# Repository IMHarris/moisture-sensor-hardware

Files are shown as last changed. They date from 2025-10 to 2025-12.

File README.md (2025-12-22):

# Moisture Sensor Hardware

KiCad hardware design for ESP32-based soil moisture monitoring system.

## Overview

This repository contains the PCB design and schematics for an irrigation moisture sensor system. The board interfaces with resistance-based moisture sensors ([I recommend Irrometer Watermark Sensors](https://www.irrometer.com/sensors.html)) and DS18B20 temperature sensors.

The board uses an [SMX moisture sensor interface](https://www.emesystems.com/smx/main.html) board to interact with up to 6 moisture sensors. The SMX board transmits AC power to the sensors which substantially reduces mineral accumulation and extends the life of the sensors.  Because moisture sensors are sensitive to temperature, the board also can take in data from DS18B20 temperature sensors through 2 available 1-Wire bus inputs.

The ESP 32 firmware combines moisture sensor and soil temperature outputs to calculate soil tension values for use in irrigation systems.  The firmware can be configured with wifi credentials so the user can access the board's web server which will display sensor values.  The firmware can also be configured with mqtt message server credentials allowing the board to transmit sensor data in formatted json via wifi to your main irrigation controller.  I am using the [SIP controller](https://github.com/Dan-in-CA/SIP) for my main irrigation system.

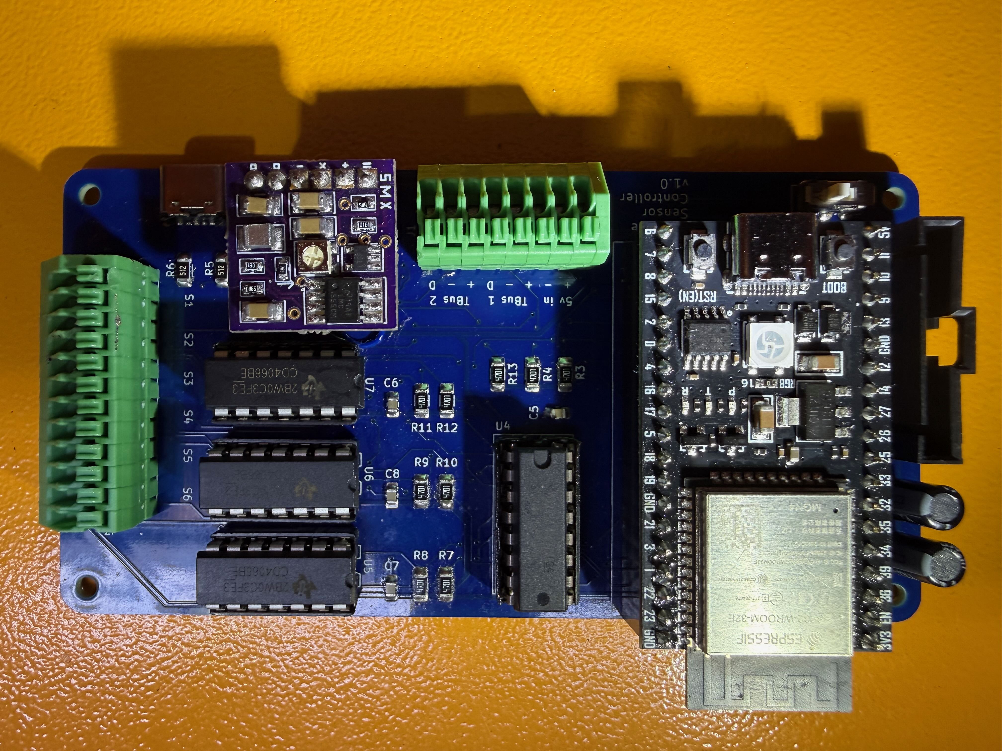
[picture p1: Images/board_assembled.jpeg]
Fully assembled board


*Board fabrication done by [PCBWay](https://www.pcbway.com) whom I can't say enough good things about: excellent website, great communication, and outstanding quality.  Their KiCad plugin makes design file uploads super easy.

## Firmware

Firmware for this hardware is available in a separate repository:
**[moisture-sensor-esp32](https://github.com/IMHarris/moisture-sensor-esp32)**

## Design Files

- **`MoistureSensor1.kicad_pro`**: KiCad project file
- **`MoistureSensor1.kicad_sch`**: Schematic design
- **`MoistureSensor1.kicad_pcb`**: PCB layout
- **`MoistureSensor1BOM.csv`**: Bill of Materials
- **`gerber/`**: Production files for PCB fabrication
- **`parts/`**: Custom component footprints and symbols

## Features

### Microcontroller
- ESP32 DevKit-compatible footprint
- WiFi connectivity for MQTT publishing
- 3.3V logic level

### Sensor Interfaces
- **6x Moisture Sensor Channels**: Relay-controlled power
- **2x OneWire Buses**: For DS18B20 temperature sensors
- **Expansion header**: Output to expand the number of moisture and temperature sensors.

### I/O
- **Moisture Sensors**: 6 channels with relay control
- **Frequency Input**: GPIO 21 (shared)
- **OneWire Buses**: GPIO 13, GPIO 14
- **OneWire Relay Control**: GPIO 12, GPIO 26
- **Status LED**: GPIO 2

### Power
- 5V input via USB or terminal
- 3.3V signal regulation for ESP32
- Relay-switched 5V outputs for moisture and temperature sensors

## Bill of Materials

See `MoistureSensor1BOM.csv` for complete component list.

Key components:
- ESP32 DevKit module.  I've used [this one](https://www.amazon.com/dp/B0D6BH4K9B?ref_=ppx_hzod_title_dt_b_fed_asin_title_0_0&th=1).
- [SMX moisture sensor interface](https://www.emesystems.com/smx/main.html)
- DS18B20 temperature sensors
- Resistance-based moisture sensors (external)
- 5V power supply

## PCB Specifications

- **Layers**: 2-layer PCB
- **Dimensions**: 111x58mm
- **Connectors**: Wire terminals for sensors, USB C or Wire terminals for power

## Manufacturing

Gerber files for PCB fabrication are included in the `gerber/` directory. These can be uploaded to PCB manufacturers like:
- [PCBWay](https://www.pcbway.com) (my favorite)

## Assembly Notes

1. Solder ESP32 DevKit module (or use pin headers for socketing)
2. Install relay modules
3. Connect terminals for sensor interfaces
4. Verify 3.3V and 5V power rails before powering ESP32
5. Flash firmware from [moisture-sensor-esp32](https://github.com/IMHarris/moisture-sensor-esp32)

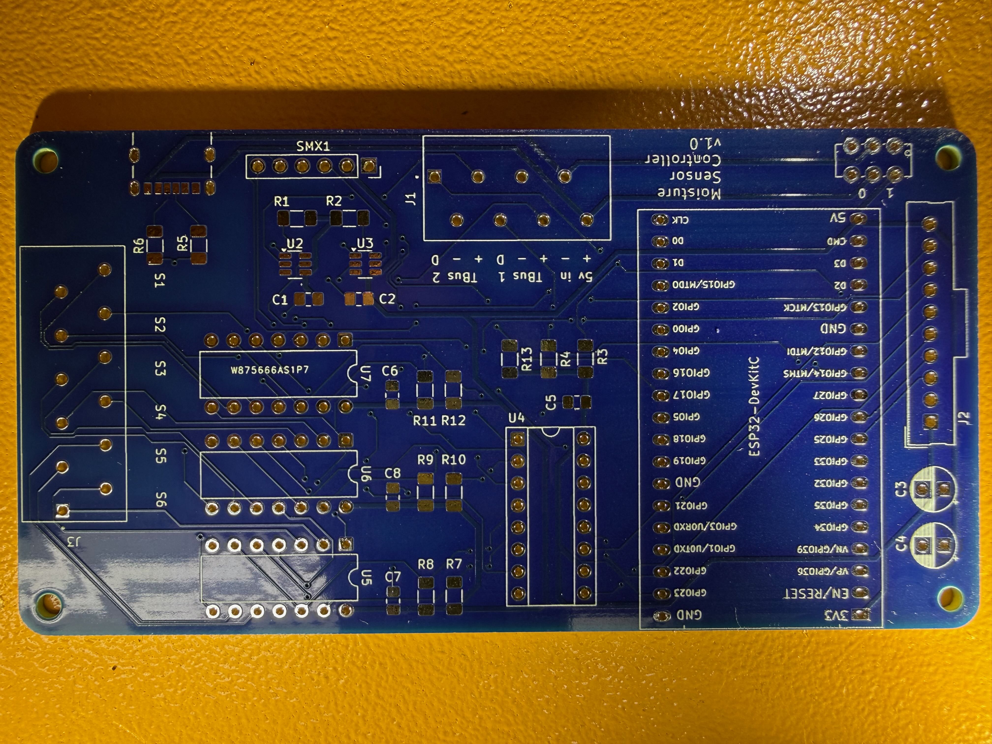
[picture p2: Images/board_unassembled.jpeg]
Board image


## Design Software

- **KiCad**: Version 7.0 or later recommended
- Open `MoistureSensor1.kicad_pro` to view/edit the design

## License

This hardware design is licensed under [CC BY-SA 4.0](http://creativecommons.org/licenses/by-sa/4.0/).

You are free to share and adapt this work, provided you give appropriate credit and distribute your contributions under the same license.

## Author

Ian Harris - [GitHub](https://github.com/IMHarris)

## Related Projects

- **Firmware**: [moisture-sensor-esp32](https://github.com/IMHarris/moisture-sensor-esp32)

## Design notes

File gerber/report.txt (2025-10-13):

Plotted to '/Users/ianharris/Tech Projects/Moisture Sensor/MoistureSensor1/MoistureSensor1-F_Cu.gbr'.
Plotted to '/Users/ianharris/Tech Projects/Moisture Sensor/MoistureSensor1/MoistureSensor1-B_Cu.gbr'.
Plotted to '/Users/ianharris/Tech Projects/Moisture Sensor/MoistureSensor1/MoistureSensor1-F_Paste.gbr'.
Plotted to '/Users/ianharris/Tech Projects/Moisture Sensor/MoistureSensor1/MoistureSensor1-B_Paste.gbr'.
Plotted to '/Users/ianharris/Tech Projects/Moisture Sensor/MoistureSensor1/MoistureSensor1-F_Silkscreen.gbr'.
Plotted to '/Users/ianharris/Tech Projects/Moisture Sensor/MoistureSensor1/MoistureSensor1-B_Silkscreen.gbr'.
Plotted to '/Users/ianharris/Tech Projects/Moisture Sensor/MoistureSensor1/MoistureSensor1-F_Mask.gbr'.
Plotted to '/Users/ianharris/Tech Projects/Moisture Sensor/MoistureSensor1/MoistureSensor1-B_Mask.gbr'.
Plotted to '/Users/ianharris/Tech Projects/Moisture Sensor/MoistureSensor1/MoistureSensor1-Edge_Cuts.gbr'.
Created Gerber job file '/Users/ianharris/Tech Projects/Moisture Sensor/MoistureSensor1/MoistureSensor1-job.gbrjob'.
Info: Done.
Info: Done.

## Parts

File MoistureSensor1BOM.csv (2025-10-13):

Id | Designator | Footprint | Quantity | Designation | Supplier and ref
1 | J2,J1 | PhoenixContact_MSTBA_2,5_2-G-5,00_1x10_2.5mm_45deg compact | 2 | Screw_Terminal_01x10
2 | J4 | Molex_SL_171971-0010_1x10_P2.54mm_Vertical | 1 | Conn_01x10_Pin
3 | R6,R4,R10,R9,R3,R11,R5,R7,R8 | R_Axial_DIN0204_L3.6mm_D1.6mm_P5.08mm_Horizontal | 9 | 4.7k
4 | R2,R1 | R_Axial_DIN0204_L3.6mm_D1.6mm_P5.08mm_Horizontal | 2 | 10k
5 | C2,C5,C6,C8,C7,C1 | C_Axial_L3.8mm_D2.6mm_P5.5mm_Horizontal | 6 | 0.1µF
6 | U3,U2 | SOT-23-6 | 2 | TPS27081ADDCR
7 | J3 | PinSocket_1x06_P2.54mm_Vertical | 1 | SMX Header
8 | U4 | DIP-16_W7.62mm_Socket | 1 | 74HC595
9 | U6,U5,U7 | DIP-14_W7.62mm | 3 | CD4066BE
10 | SW1 | DPDT Slide switch - CL-SB-22C-02 | 1 | SW_Slide_DPDT
11 | C4,C3 | CP_Radial_D5.0mm_P2.50mm | 2 | 10µF
12 | U1 | ESP32-DevKitC | 1 | ESP32-DevKitC

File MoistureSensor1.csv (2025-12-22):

Reference | Qty | Value | DNP | Exclude from BOM | Exclude from Board | Footprint | Datasheet
5v in1 | 1 | 10164359-00011LF |  |  |  | Ians_Parts:AMPHENOL_10164359-00011LF
C1,C2,C5,C6,C7,C8 | 6 | 0.1µF |  |  |  | Capacitor_SMD:C_0805_2012Metric_Pad1.18x1.45mm_HandSolder
C3,C4 | 2 | 10µF |  |  |  | Capacitor_THT:CP_Radial_D5.0mm_P2.50mm | https://www.rubycon.co.jp/wp-content/uploads/catalog-aluminum/YXJ.pdf,~
DPDT1 | 1 | SW_Slide_DPDT |  |  |  | Ians_Parts:DPDT Slide switch - CL-SB-22C-02 | https://www.nidec-components.com/e/catalog/switch/cl-sb.pdf
H1,H2,H3,H4 | 4 | MountingHole |  | Excluded from BOM |  | MountingHole:MountingHole_2.7mm_M2.5_ISO14580 | ~
J1 | 1 | Screw_Terminal_01x08 |  |  |  | Ians_Parts:PHOENIX_1990067 | https://mm.digikey.com/Volume0/opasdata/d220001/medias/docus/2515/COMBICON%20Spring-Cage%20PCB%20Term.%20Blocks.pdf
J2 | 1 | Expansion |  |  |  | Connector_Molex:Molex_SL_171971-0010_1x10_P2.54mm_Vertical | https://www.molex.com/content/dam/molex/molex-dot-com/products/automated/en-us/salesdrawingpdf/705/70543/705430042_sd.pdf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
J3 | 1 | Screw_Terminal_01x12 |  |  |  | Ians_Parts:PHOENIX_1990106 | https://mm.digikey.com/Volume0/opasdata/d220001/medias/docus/2515/COMBICON%20Spring-Cage%20PCB%20Term.%20Blocks.pdf
R1,R2 | 2 | 10k |  |  |  | Resistor_SMD:R_1206_3216Metric_Pad1.30x1.75mm_HandSolder
R3,R4,R7,R8,R9,R10,R11,R12,R13 | 9 | 4.7k |  |  |  | Resistor_SMD:R_1206_3216Metric_Pad1.30x1.75mm_HandSolder
R5,R6 | 2 | 5.1k |  |  |  | Resistor_SMD:R_1206_3216Metric_Pad1.30x1.75mm_HandSolder
SMX1 | 1 | SMX Header |  |  |  | Connector_PinSocket_2.54mm:PinSocket_1x06_P2.54mm_Vertical | ~
U1 | 1 | ESP32-DevKitC |  |  |  | PCM_Espressif:ESP32-DevKitC | https://docs.espressif.com/projects/esp-idf/zh_CN/latest/esp32/hw-reference/esp32/get-started-devkitc.html
U2,U3 | 2 | TPS27081ADDCR |  |  |  | Package_TO_SOT_SMD:SOT-23-6 | https://www.ti.com/lit/ds/symlink/tps27081a.pdf?HQS=dis-dk-null-digikeymode-dsf-pf-null-wwe&ts=1754869477035
U4 | 1 | 74HC595 |  |  |  | Package_DIP:DIP-16_W7.62mm_Socket | http://www.ti.com/lit/ds/symlink/sn74hc595.pdf
U5,U6,U7 | 3 | CD4066BE |  |  |  | Package_DIP:DIP-14_W7.62mm | https://www.ti.com/lit/ds/symlink/cd4066b.pdf

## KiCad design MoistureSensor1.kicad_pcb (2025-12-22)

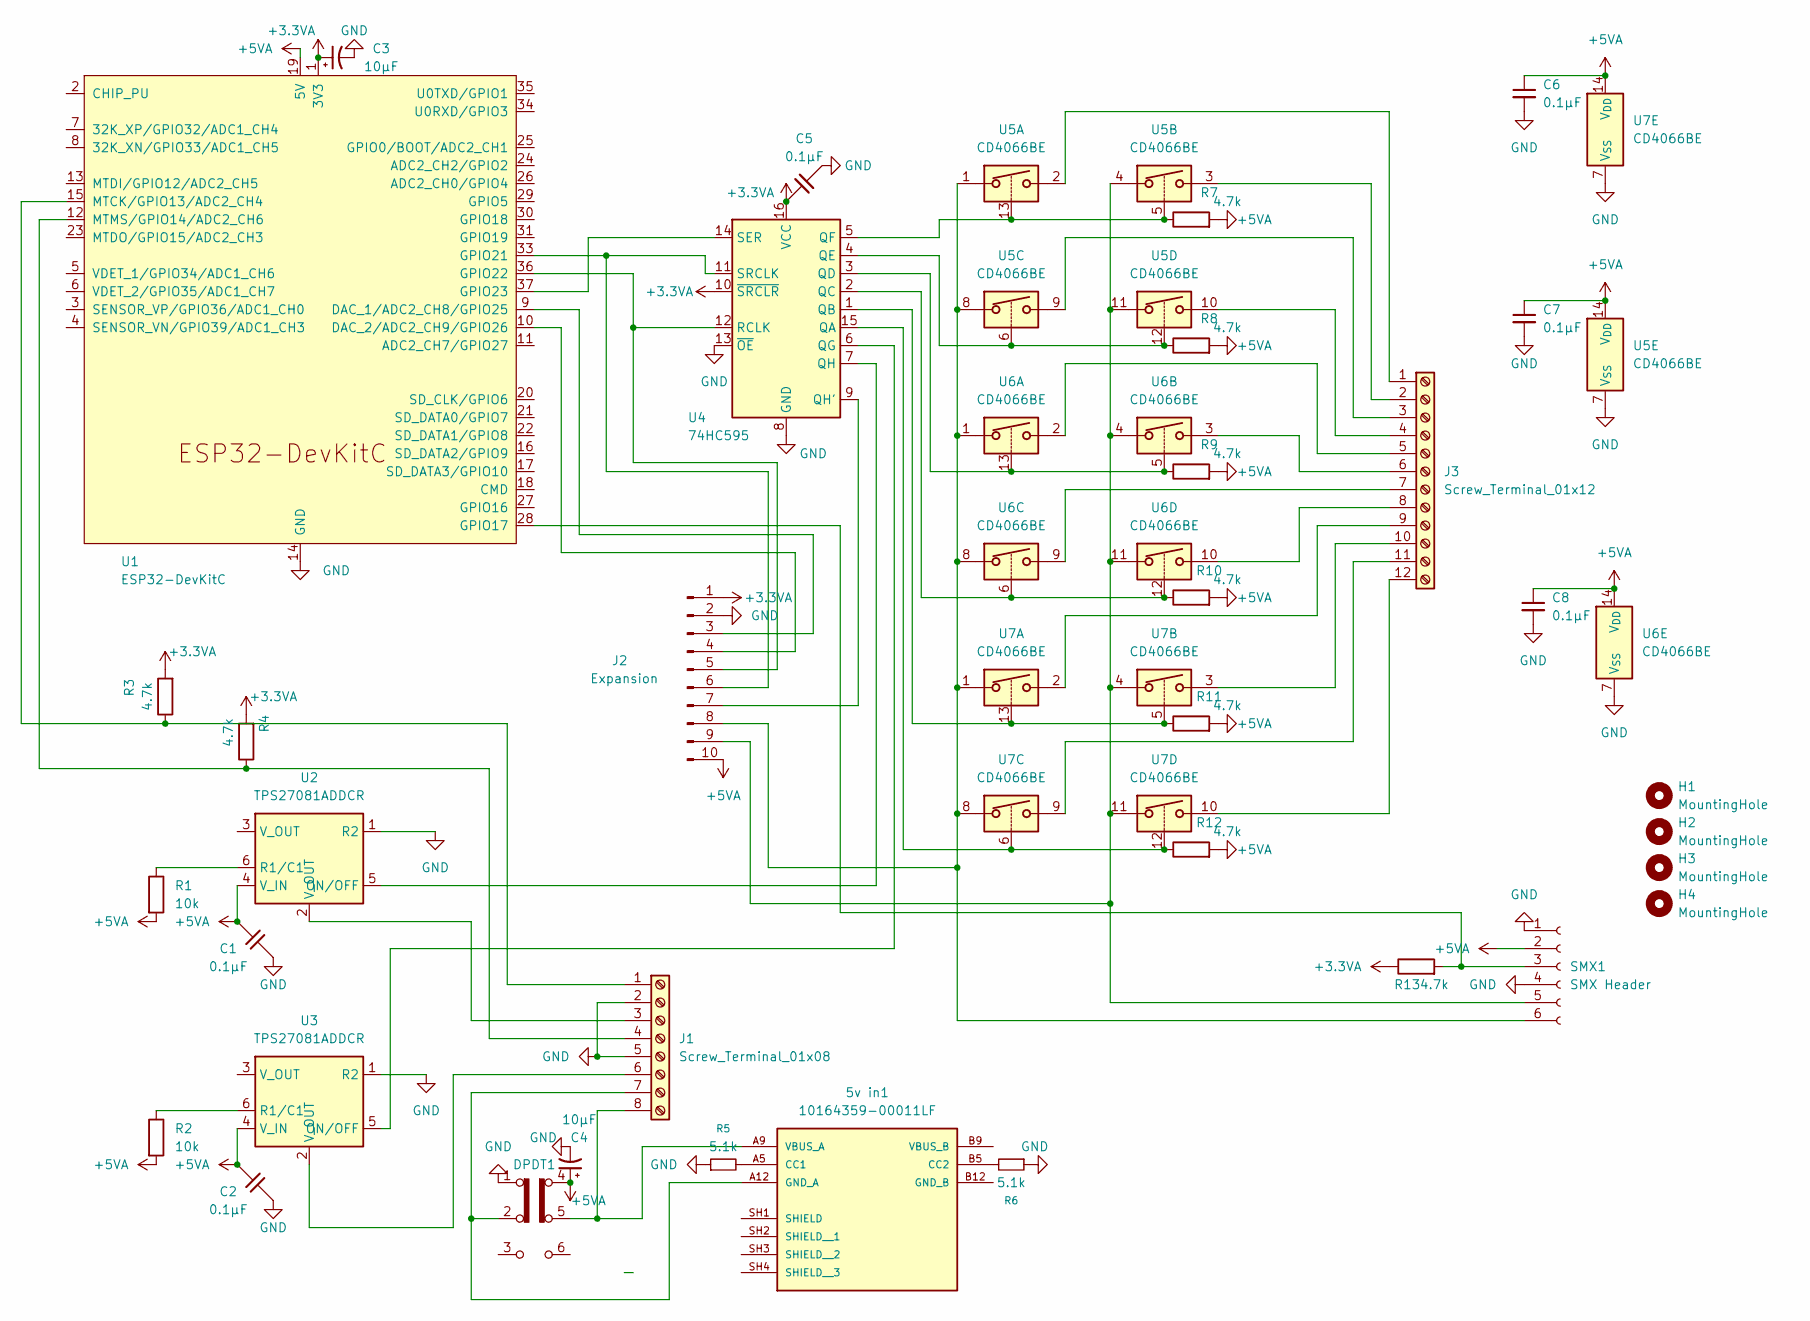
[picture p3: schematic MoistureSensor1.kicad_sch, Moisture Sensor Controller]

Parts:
5v in1: 10164359-00011LF; AMPHENOL_10164359-00011LF; PARTREV A
C1, C2, C5, C6, C7, C8: 0.1µF; C_0805_2012Metric_Pad1.18x1.45mm_HandSolder
C3, C4: 10µF; CP_Radial_D5.0mm_P2.50mm
DPDT1: SW_Slide_DPDT; DPDT Slide switch - CL-SB-22C-02
H1, H2, H3, H4: MountingHole; MountingHole_2.7mm_M2.5_ISO14580
J1: Screw_Terminal_01x08; PHOENIX_1990067
J2: Expansion; Molex_SL_171971-0010_1x10_P2.54mm_Vertical
J3: Screw_Terminal_01x12; PHOENIX_1990106
R1, R2: 10k; R_1206_3216Metric_Pad1.30x1.75mm_HandSolder
R3, R4, R7, R8, R9, R10, R11, R12, R13: 4.7k; R_1206_3216Metric_Pad1.30x1.75mm_HandSolder
R5, R6: 5.1k; R_1206_3216Metric_Pad1.30x1.75mm_HandSolder
SMX1: SMX Header; PinSocket_1x06_P2.54mm_Vertical
U1: ESP32-DevKitC
U2, U3: TPS27081ADDCR; SOT-23-6
U4: 74HC595; DIP-16_W7.62mm_Socket
U5, U6, U7: CD4066BE; DIP-14_W7.62mm

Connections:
+3.3VA: C3.1, C5.2, J2.1, R3.2, R4.2, R13.1, U1.1 (3V3), U4.10 (~SRCLR), U4.16 (VCC)
+5VA: C1.2, C2.2, C4.1, C6.1, C7.1, C8.1, DPDT1.4 (C), J2.10, R1.2, R2.2, R7.2, R8.2, R9.2, R10.2, R11.2, R12.2, SMX1.2, U1.19 (5V), U2.4 (V_IN), U3.4 (V_IN), U5.14 (V_{DD}), U6.14 (V_{DD}), U7.14 (V_{DD})
GND: C1.1, C2.1, C3.2, C4.2, C5.1, C6.2, C7.2, C8.2, DPDT1.1 (A), J1.2, J1.5, J2.2, R5.1, R6.1, SMX1.1, SMX1.4, U1.14 (GND), U1.32 (GND), U1.38 (GND), U2.1 (R2), U3.1 (R2), U4.8 (GND), U4.13 (~OE), U5.7 (V_{SS}), U6.7 (V_{SS}), U7.7 (V_{SS})
unnamed: 5v in1.A5 (CC1), R5.2
unnamed: 5v in1.B5 (CC2), R6.2
unnamed: 5v in1.A12 (GND_A), DPDT1.2 (B), J1.7
unnamed: 5v in1.A9 (VBUS_A), DPDT1.5 (B), J1.8
unnamed: J1.1, R3.1, U1.15 (MTCK/GPIO13/ADC2_CH4)
unnamed: J1.3, U2.2 (V_OUT)
unnamed: J1.4, R4.1, U1.12 (MTMS/GPIO14/ADC2_CH6)
unnamed: J1.6, U3.2 (V_OUT)
unnamed: J2.3, U1.9 (DAC_1/ADC2_CH8/GPIO25)
unnamed: J2.4, U1.10 (DAC_2/ADC2_CH9/GPIO26)
unnamed: J2.5, U1.36 (GPIO22), U4.12 (RCLK)
unnamed: J2.6, U1.33 (GPIO21), U4.11 (SRCLK)
unnamed: J2.7, U4.9 (QH')
unnamed: J2.8, SMX1.6, U5.1, U5.8, U6.1, U6.8, U7.1, U7.8
unnamed: J2.9, SMX1.5, U5.4, U5.11, U6.4, U6.11, U7.4, U7.11
unnamed: J3.1, U5.2
unnamed: J3.2, U5.3
unnamed: J3.3, U5.9
unnamed: J3.4, U5.10
unnamed: J3.5, U6.2
unnamed: J3.6, U6.3
unnamed: J3.7, U6.9
unnamed: J3.8, U6.10
unnamed: J3.9, U7.2
unnamed: J3.10, U7.3
unnamed: J3.11, U7.9
unnamed: J3.12, U7.10
unnamed: R13.2, SMX1.3, U1.28 (GPIO17)
unnamed: U1.37 (GPIO23), U4.14 (SER)
unnamed: U2.5 (ON/OFF), U4.7 (QH)
unnamed: R1.1, U2.6 (R1/C1)
unnamed: U3.5 (ON/OFF), U4.6 (QG)
unnamed: R2.1, U3.6 (R1/C1)
unnamed: R12.1, U4.15 (QA), U7.6, U7.12
unnamed: R11.1, U4.1 (QB), U7.5, U7.13
unnamed: R10.1, U4.2 (QC), U6.6, U6.12
unnamed: R9.1, U4.3 (QD), U6.5, U6.13
unnamed: R8.1, U4.4 (QE), U5.6, U5.12
unnamed: R7.1, U4.5 (QF), U5.5, U5.13

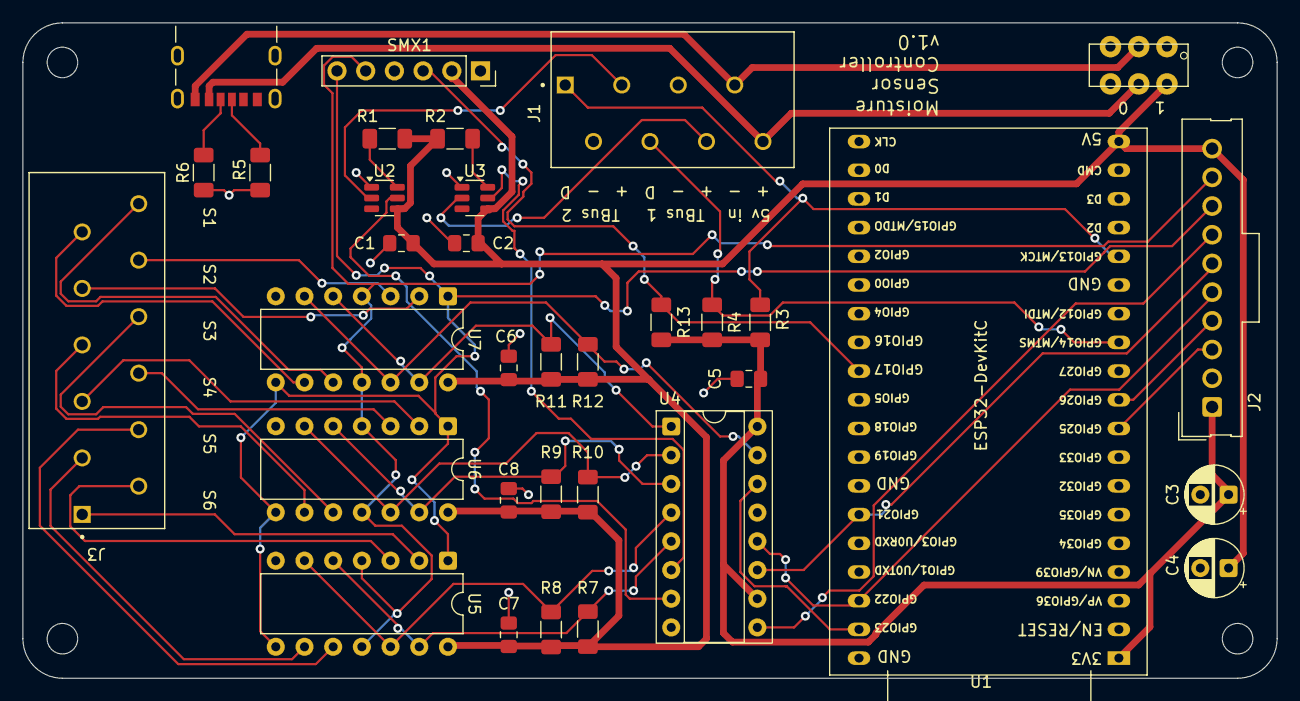
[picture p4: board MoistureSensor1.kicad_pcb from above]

Board: 2 copper layers, 111.0 x 58.0 mm, 38 parts (0 on the bottom side), 42 nets.

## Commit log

2025-10-13 Initial commit: KiCad hardware design for ESP32 moisture sensor
    - PCB layout and schematic for ESP32-based system
    - 6 moisture sensor channels with relay control
    - Dual OneWire buses for DS18B20 temperature sensors
    - Gerber files for PCB fabrication
    - Bill of materials
    [MoistureSensor1-B_Cu.gbr, MoistureSensor1-B_Mask.gbr, MoistureSensor1-B_Paste.gbr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]
2025-11-29 Misc updates
    Miscellaneous updates
    [MoistureSensor1-B_Cu.gbr, MoistureSensor1-B_Mask.gbr, MoistureSensor1-B_Paste.gbr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]
2025-12-22 Small adjustments
    Small adjustments
    [MoistureSensor1.csv, MoistureSensor1.kicad_pcb]
